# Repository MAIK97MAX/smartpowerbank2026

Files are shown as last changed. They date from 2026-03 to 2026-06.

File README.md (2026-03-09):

# Semesterproject 2026 - Smart Powerbank

## Authors
Jukic Malik & Sayfutdinov David - HTL Rankweil

## Goal 
The goal of this project is to design and build a smart power bank with USB-C charging, battery management and system monitoring.

## Features
- USB-C charging
- OLED display for battery status and system information
- ESP8266 module for web interface
- Battery monitoring and protection

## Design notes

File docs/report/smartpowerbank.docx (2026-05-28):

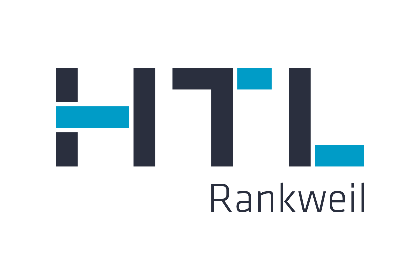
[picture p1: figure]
HTL Rankweil - Technik_begeistert

Semesterprojekt 2026

Smart Powerbank

Jukic Malik und Sayfutdinov David

HTL Rankweil

4AHEL

HWE-Übungen

Projektbetreuer: Herr Lauritsch

02.03.2026

# 1. Einleitung

## 1.1. Motivation

Mit zunehmender Nutzung von mobilen Geräten wie Smartphones, Tablets und Wearables steigt auch der Bedarf an mobiler und zuverlässiger Energieversorgung. Besonders im Alltag, auf Reisen oder im Outdoor-Bereich sind Powerbanks zu einem essenziellen Bestandteil der modernen Technik geworden.

Konventionelle Powerbanks erfüllen zwar ihre Aufgabe der mobilen Spannungsversorgung, doch weisen oft gewisse Einschränkungen auf. Informationen über den tatsächlichen Ladezustand, den Energieverbrauch oder die Effizienz stehen dem Nutzer meist nur eingeschränkt zur Verfügung.

Darüber hinaus besitzen viele handelsübliche Geräte keine detaillierte Überwachung relevanter Betriebsparameter wie Strom, Spannung oder Temperatur. Eine fehlende systematische Erfassung dieser Daten kann zu ineffizienter Energienutzung, verkürzter Lebensdauer der Akkuzellen sowie sicherheitstechnischen Risiken führen. Auch eine Aufzeichnung und Analyse des Betriebsverhaltens ist in herkömmlichen Lösungen in der Regel nicht vorgesehen.

Die Entwicklung einer Smart Powerbank bietet daher die Möglichkeit, Energiespeicherung, Leistungselektronik und intelligente Zustandsüberwachung in einem integrierten System zu vereinen. Neben einer stabilen und effizienten Spannungsregelung steht insbesondere die transparente Darstellung relevanter Systemparameter im Mittelpunkt.

Im Rahmen dieses Semesterprojekts wird daher eine intelligente Powerbank entwickelt, welche über ein erweitertes Energiemanagement verfügt sowie eine kontinuierliche Überwachung des Batteriezustandes ermöglicht.

## 1.2. Zielsetzung

Ziel dieses Semesterprojekts ist die Entwicklung und Realisierung einer intelligenten Powerbank auf Basis eines 1S-LiPo-Akkusystems mit einer nominalen Zellspannung von 3,7 V mit einer Kapazität von 8000 mAh.

Die Powerbank soll eine geregelte Ausgangsspannung von 5V bei einem maximalen Ausgangsstrom von 3 A bereitstellen. Die maximale Ausgangsleistung beträgt somit bis zu 15 W. Die Spannungswandlung erfolgt über eine geeignete DC/DC-Topologie mit einem angestrebten Gesamtwirkungsgrad von mindestens 80 % im Nennlastbereich.

Ein wesentlicher Bestandteil des Projekts ist die Implementierung eines erweiterten Energiemanagementsystems auf Basis eines ATmega328A-Mikrocontrollers. Ziel ist die kontinuierliche Erfassung und Verarbeitung relevanter Betriebsparameter, darunter:

– Ausgangsstrom und Ausgangsspannung mittels INA219-Messbausteinen
– Temperaturüberwachung des Akkusystems über einen NTC
– Berechnung der momentanen Ausgangsleistung
– Abschätzung des Ladezustands und der verbleibenden Entladedauer

Die erfassten Systemdaten sollen dem Nutzer über ein mehrstufiges Anzeigesystem zugänglich gemacht werden. Das Display umfasst verschiedene Betriebsmodi, darunter eine Startansicht mit Zeit- und Statusinformationen, eine Live-Ansicht der elektrischen Kenngrößen sowie eine detaillierte Batterieübersicht mit Zustands- und Verlaufsinformationen.

Zusätzlich wird ein ESP8266-Modul integriert, welches als Access Point fungiert und eine webbasierte Benutzeroberfläche bereitstellt. Ziel ist die drahtlose Anzeige von Betriebsdaten, Systeminformationen sowie gespeicherten Verlaufswerten. Die Zeitsynchronisation erfolgt über das Internet, wobei Datum und Uhrzeit mithilfe des ATmega328 dauerhaft gespeichert werden.

Neben der funktionalen Umsetzung steht insbesondere die systematische Integration von Leistungselektronik, Messdatenerfassung, Mikrocontroller-Steuerung und drahtloser Kommunikation im Fokus. Das Projekt verfolgt somit das Ziel, eine technisch fundierte, modular aufgebaute und praxisnahe Smart-Powerbank-Lösung zu realisieren.

## 1.3 Abgrenzungen des Projekts

Für dieses Projekt wurden bewusst einige Abgrenzungen (Nicht-Ziele) festgelegt welche nicht im Rahmen dieses Projekts liegen und zu unnötigen Verkomplizierungen und Ableitungen vom eigentlichen Thema führen würden.

Implementierung des USB-C Power-Delivery-(PD)-Protokolls
Die Ausgangsspannung wird bewusst auf eine feste 5V-Versorgung mit maximal 3A begrenzt. Die Umsetzung variabler Spannungsprofile gemäß USB-PD würde zusätzliche Protokoll-Controller sowie eine deutlich komplexere Leistungsregelung erfordern und liegt außerhalb des definierten Projektumfangs.

– Nutzung des ESP8266 als Router oder Internet-Gateway
Der ESP8266 dient ausschließlich zur Bereitstellung eines lokalen Access Points und zur Anzeige der webbasierten Benutzeroberfläche. Eine Weiterleitung von Internetverkehr oder eine Nutzung als Netzwerkinfrastrukturkomponente ist nicht vorgesehen.

– Smartphone-App-Entwicklung
Die Anzeige der Systemdaten erfolgt ausschließlich über das integrierte Display und ein webbasiertes Interface. Die Entwicklung einer Smartphone-App ist nicht Teil des Projekts.

## 1.4 Aufbau der Arbeit

In Kapitel 2 werden die notwendigen Technischen Grundlagen und Überlegungen für das System ermittelt und erläutert. In Kapitel 3…

# 2. Technische Grundlagen

## 2.1 Systemüberblick

Eine Powerbank unterteilt sich in 2 Hauptsysteme:

- Akkusystem (Akkuzelle, BMS, Laderegler, Fuel Cell)
- Spannungsregelung für den Ausgang

Zusätzlich zu diesen erfordert dieses Projekt weitere Systeme:

- Spannungs- und Strommessung
- Batterieüberwachung
- Live-Anzeige
- Steuerung
- Wi-Fi-Modul für Webserver-Anzeige

## 2.2 Realisierung

Vorerst veranschaulicht ein Blockschaltbild die Zusammenhänge und Kommunikation der Systeme.

### 2.2.1 Spannungs- und Strommessung

Für die Spannungs- und Strommessung der Ausgänge der Powerbank wird ein INA219 Current Monitor von Texas Instruments eingesetzt.

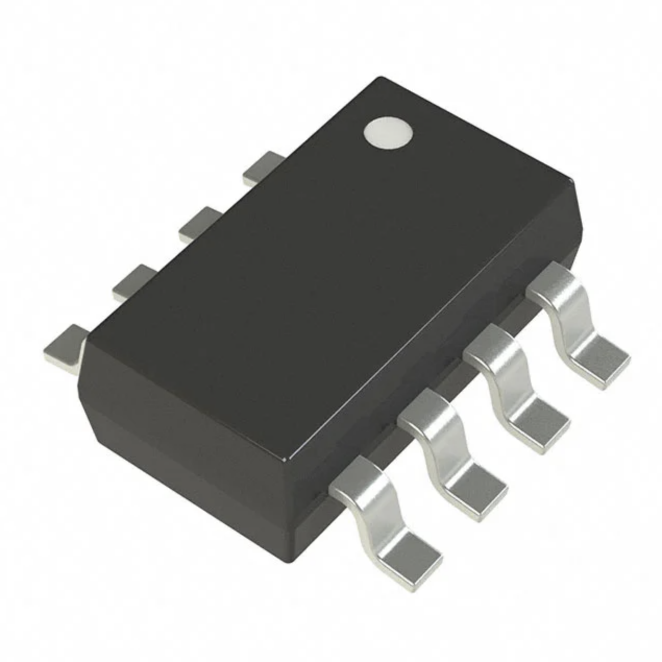
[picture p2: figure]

INA219

https://www.ti.com/product/de-de/INA219#tech-docs

Wichtige Kenndaten:

- I²C
- 12-Bit ADC
- Vs – 3,3V

Smart Powerbank Jukic M. & Sayfutdinov D.

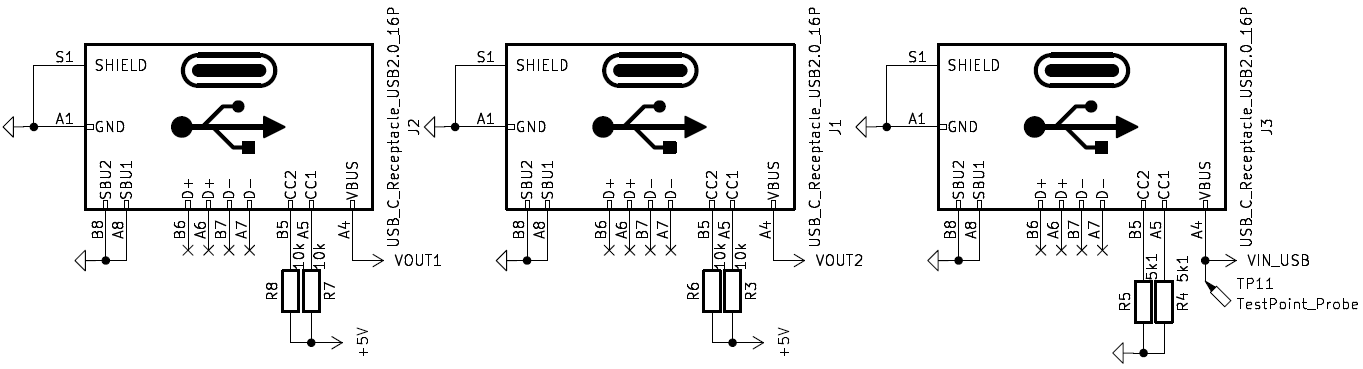
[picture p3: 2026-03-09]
docs/images/usbc-conn.png

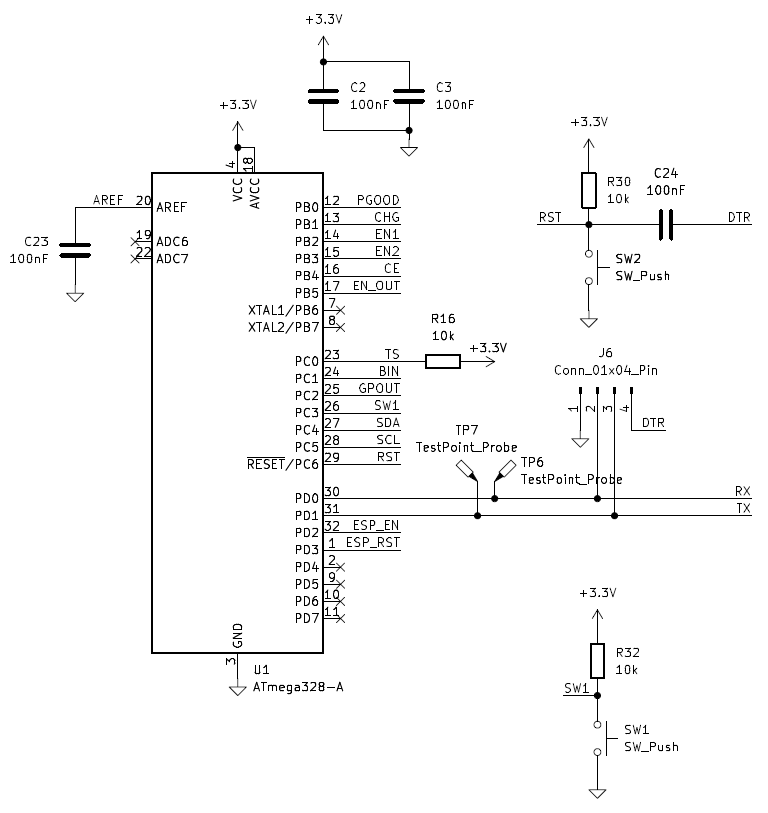
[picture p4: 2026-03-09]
docs/images/atmega328p.png

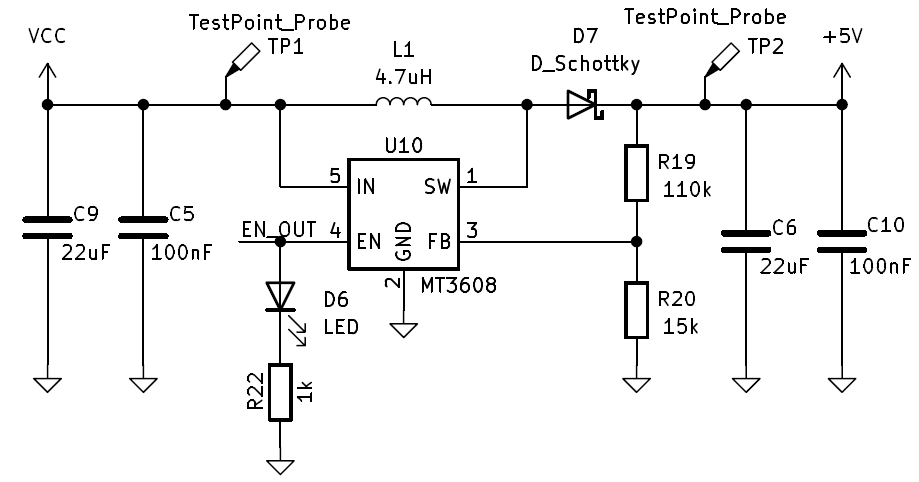
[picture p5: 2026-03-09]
docs/images/mt3608.png

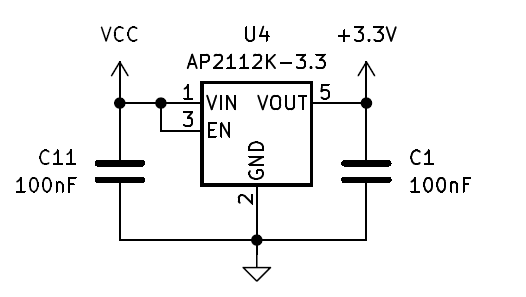
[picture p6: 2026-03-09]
docs/images/ap2112k.png

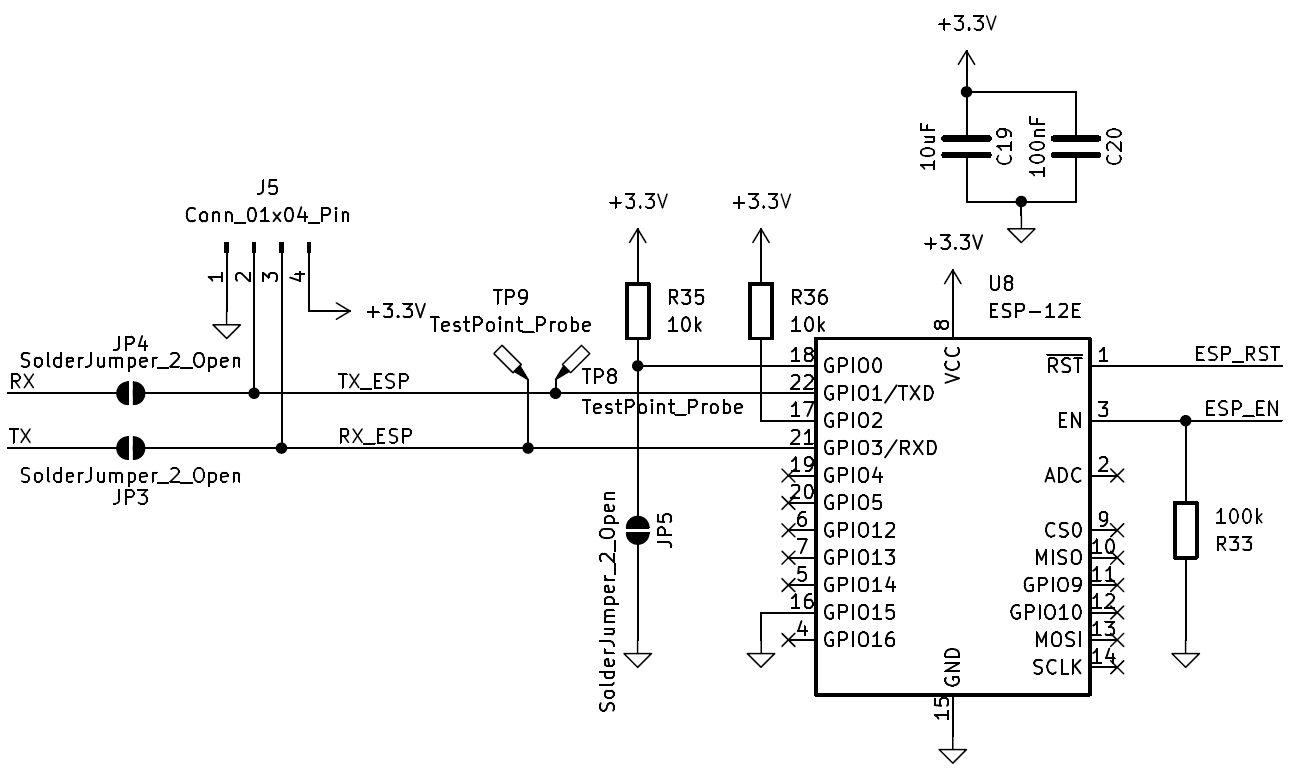
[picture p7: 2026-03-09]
docs/images/esp8266.png

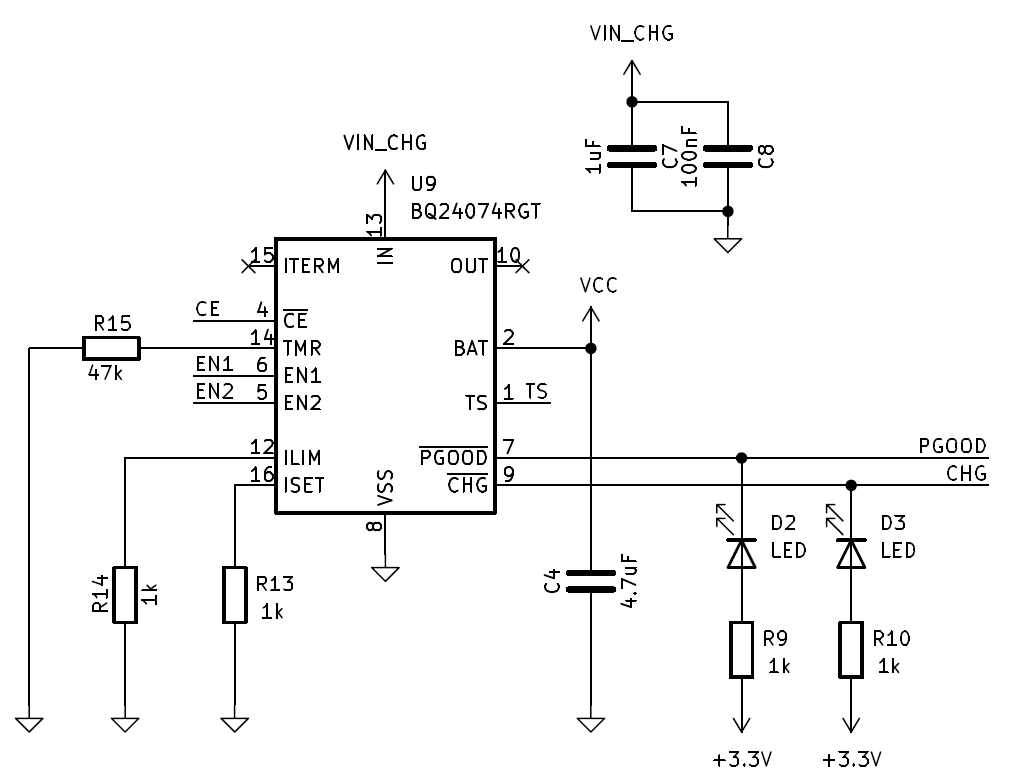
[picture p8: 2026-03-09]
docs/images/bq24074.png

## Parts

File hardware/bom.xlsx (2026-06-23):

Reference | Qty | Value | Footprint
C1,C2,C3,C4,C5,C6,C8,C12,C13,C15,C18,C20,C22 | 13 | 100nF | Capacitor_SMD:C_0603_1608Metric
C7,C17 | 2 | 1uF | Capacitor_SMD:C_0805_2012Metric
C9,C10,C19 | 3 | 10uF | Capacitor_SMD:C_0805_2012Metric
C11 | 1 | 470nF | Capacitor_SMD:C_0603_1608Metric
C14,C21 | 2 | 22uF | Capacitor_SMD:C_0805_2012Metric
C16 | 1 | 4.7uF | Capacitor_SMD:C_0603_1608Metric
D1,D2,D3,D5 | 4 | LED | LED_SMD:LED_0603_1608Metric
D4 | 1 | D_Schottky | Diode_SMD:D_SMA
D6 | 1 | n.b. | LED_SMD:LED_0603_1608Metric
J1,J2,J4 | 3 | USB_C_Receptacle_USB2.0_16P | Connector_USB:USB_C_Receptacle_GCT_USB4110
J3,J7 | 2 | Conn_01x04_Pin | Connector_PinHeader_2.54mm:PinHeader_1x04_P2.54mm_Vertical
J5 | 1 | Conn_01x04_Pin | Connector_PinSocket_2.54mm:PinSocket_1x04_P2.54mm_Vertical
J6 | 1 | Conn_01x03_Pin | Connector_PinHeader_2.54mm:PinHeader_1x03_P2.54mm_Vertical
JP1,JP2,JP3 | 3 | SolderJumper_2_Open | Jumper:SolderJumper-2_P1.3mm_Open_RoundedPad1.0x1.5mm
L1 | 1 | 4.7uH | Inductor_SMD:L_Coilcraft_XAL4030-XXX
R1,R2,R3,R4,R5,R6,R7,R20,R21 | 9 | 10k | Resistor_SMD:R_0603_1608Metric
R8,R9 | 2 | 5k1 | Resistor_SMD:R_0603_1608Metric
R10,R11 | 2 | 3.3k | Resistor_SMD:R_0603_1608Metric
R12,R14,R15 | 3 | 0.01 | Resistor_SMD:R_2512_6332Metric
R13,R16,R18,R19,R22,R23 | 6 | 1k | Resistor_SMD:R_0603_1608Metric
R17 | 1 | 47k | Resistor_SMD:R_0603_1608Metric
R24 | 1 | 110k | Resistor_SMD:R_0603_1608Metric
R25 | 1 | 15k | Resistor_SMD:R_0603_1608Metric
R26 | 1 | 100k | Resistor_SMD:R_0603_1608Metric
R27 | 1 | n.b. | Resistor_SMD:R_0603_1608Metric
SW1,SW2 | 2 | SW_Push | Button_Switch_SMD:SW_SPST_B3S-1000
TP1,TP2,TP3,TP4,TP5,TP6,TP7,TP8,TP9,TP10,TP11,TP12 | 12 | TestPoint_Probe | Connector_PinHeader_1.00mm:PinHeader_1x01_P1.00mm_Vertical
U1 | 1 | ATmega328-A | Package_QFP:TQFP-32_7x7mm_P0.8mm
U2 | 1 | AP2112K-3.3 | Package_TO_SOT_SMD:SOT-23-5
U3,U4 | 2 | INA219AxD | Package_SO:SOIC-8_3.9x4.9mm_P1.27mm
U5 | 1 | BQ27441-G1 | Package_SON:Texas_S-PDSO-N12
U6 | 1 | BQ24074RGT | Package_DFN_QFN:VQFN-16-1EP_3x3mm_P0.5mm_EP1.6x1.6mm
U7 | 1 | MT3608 | Package_TO_SOT_SMD:SOT-23-6
U8 | 1 | ESP-12E | RF_Module:ESP-12E

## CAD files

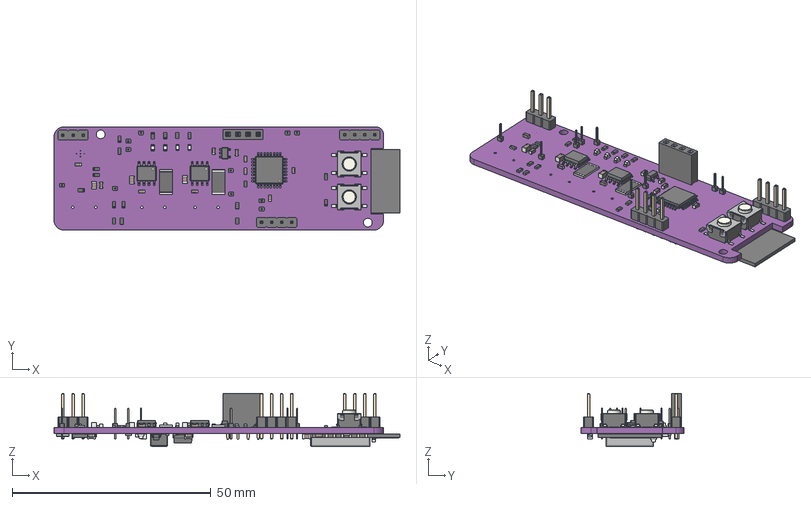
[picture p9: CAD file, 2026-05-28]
hardware/3dmodels/board.step
87.1 x 26.0 x 13.4 mm
TQFP-32_7x7mm_P0.8mm
R_0603_1608Metric x 24
SOIC-8_3.9x4.9mm_P1.27mm x 2
C_0603_1608Metric x 15
PinHeader_1x01_P1.00mm_Vertical x 11
SW_SPST_B3S-1000 x 2
LED_0603_1608Metric x 5
PinHeader_1x04_P2.54mm_Vertical x 2
C_0805_2012Metric x 7
SOT-23-5
R_2512_6332Metric x 3
PinHeader_1x03_P2.54mm_Vertical
PinSocket_1x04_P2.54mm_Vertical
L_Coilcraft_XAL4030-XXX
ESP-12E
D_SMA
SOT-23-6
Texas_S-PDSO-N12
Smart_Powerbank_Jukic_Sayfutdinov_PCB

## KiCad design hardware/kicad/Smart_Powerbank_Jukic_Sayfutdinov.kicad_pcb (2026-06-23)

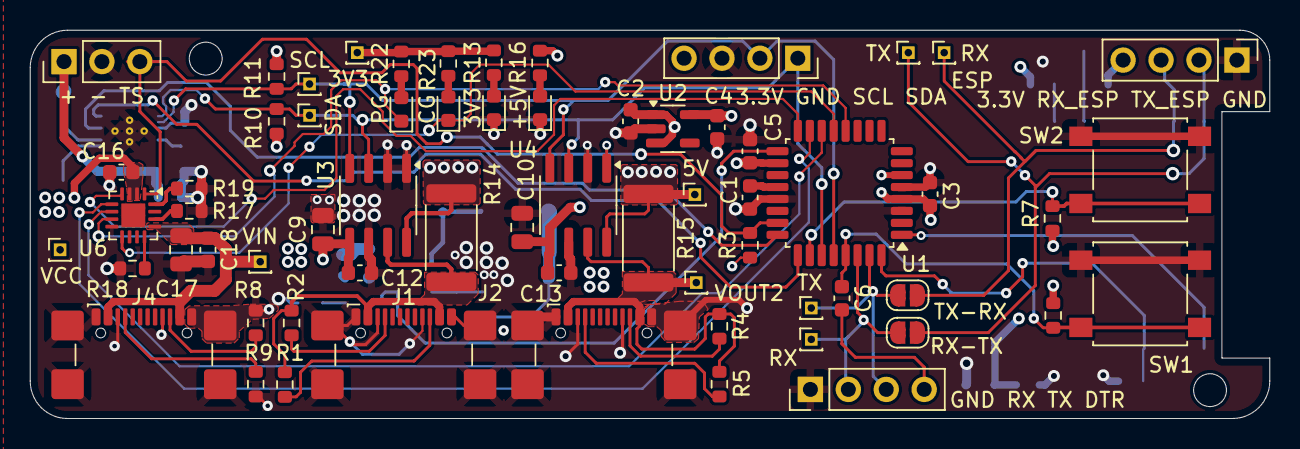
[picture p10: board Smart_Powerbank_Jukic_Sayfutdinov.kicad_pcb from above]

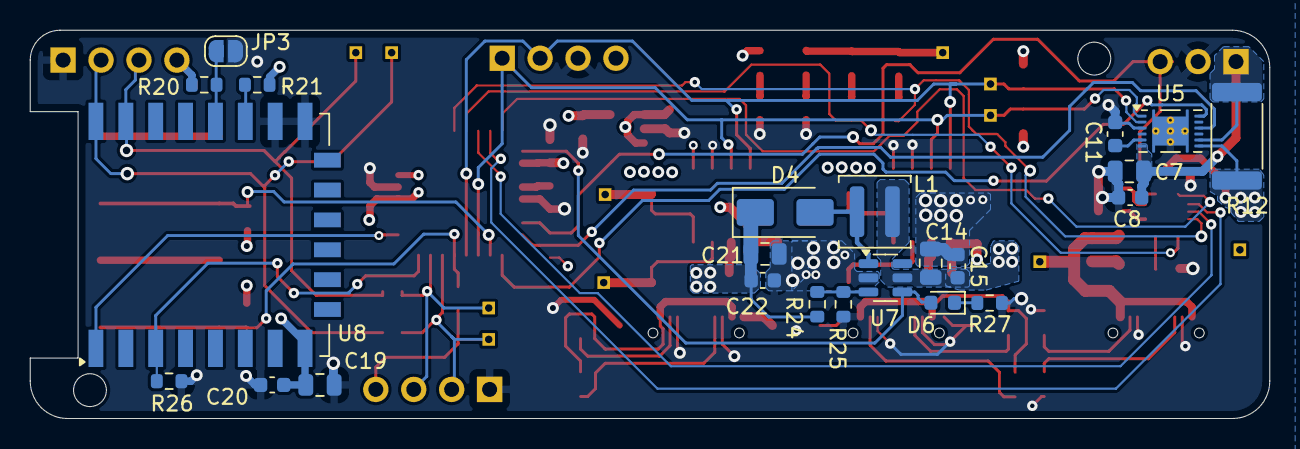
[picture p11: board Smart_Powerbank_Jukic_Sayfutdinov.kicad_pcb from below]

Board: 4 copper layers, 83.0 x 26.0 mm, 87 parts (23 on the bottom side), 48 nets.

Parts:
3.3V GND SCL SDA: Conn_01x04_Pin; PinSocket_1x04_P2.54mm_Vertical
3.3V RX_ESP TX_ESP GND: Conn_01x04_Pin; PinHeader_1x04_P2.54mm_Vertical
3V3: LED; LED_0603_1608Metric
3V3#2, 5V: TestPoint_Probe; PinHeader_1x01_P1.00mm_Vertical
+5V: LED; LED_0603_1608Metric
+ - TS: Conn_01x03_Pin; PinHeader_1x03_P2.54mm_Vertical
C1, C2, C3, C4, C5, C6, C8, C12, C13, C15, C18, C20, C22: 100nF; C_0603_1608Metric
C7, C17: 1uF; C_0805_2012Metric
C9, C10, C19: 10uF; C_0805_2012Metric
C11: 470nF; C_0603_1608Metric
C14, C21: 22uF; C_0805_2012Metric
C16: 4.7uF; C_0603_1608Metric
CG: LED; LED_0603_1608Metric
D4: D_Schottky; D_SMA
D6: n.b.; LED_0603_1608Metric
GND RX TX DTR: Conn_01x04_Pin; PinHeader_1x04_P2.54mm_Vertical
J1, J2, J4: USB_C_Receptacle_USB2.0_16P; USB_C_Receptacle_GCT_USB4110
JP3: SolderJumper_2_Open; SolderJumper-2_P1.3mm_Open_RoundedPad1.0x1.5mm
L1: 4.7uH; L_Coilcraft_XAL4030-XXX
PG: LED; LED_0603_1608Metric
R1, R2, R3, R4, R5, R6, R7, R20, R21: 10k; R_0603_1608Metric
R8, R9: 5k1; R_0603_1608Metric
R10, R11: 3.3k; R_0603_1608Metric
R12, R14, R15: 0.01; R_2512_6332Metric
R13, R16, R18, R19, R22, R23: 1k; R_0603_1608Metric
R17: 47k; R_0603_1608Metric
R24: 110k; R_0603_1608Metric
R25: 15k; R_0603_1608Metric
R26: 100k; R_0603_1608Metric
R27: n.b.; R_0603_1608Metric
RX: TestPoint_Probe; PinHeader_1x01_P1.00mm_Vertical
RX#2: TestPoint_Probe; PinHeader_1x01_P1.00mm_Vertical
RX-TX: SolderJumper_2_Open; SolderJumper-2_P1.3mm_Open_RoundedPad1.0x1.5mm
SCL: TestPoint_Probe; PinHeader_1x01_P1.00mm_Vertical
SDA: TestPoint_Probe; PinHeader_1x01_P1.00mm_Vertical
SW1, SW2: SW_Push; SW_SPST_B3S-1000
TX: TestPoint_Probe; PinHeader_1x01_P1.00mm_Vertical
TX#2: TestPoint_Probe; PinHeader_1x01_P1.00mm_Vertical
TX-RX: SolderJumper_2_Open; SolderJumper-2_P1.3mm_Open_RoundedPad1.0x1.5mm
U1: ATmega328-A; TQFP-32_7x7mm_P0.8mm
U2: AP2112K-3.3; SOT-23-5
U3, U4: INA219AxD; SOIC-8_3.9x4.9mm_P1.27mm
U5: BQ27441-G1; Texas_S-PDSO-N12
U6: BQ24074RGT; VQFN-16-1EP_3x3mm_P0.5mm_EP1.6x1.6mm
U7: MT3608; SOT-23-6
U8: ESP-12E
VCC: TestPoint_Probe; PinHeader_1x01_P1.00mm_Vertical
VIN: TestPoint_Probe; PinHeader_1x01_P1.00mm_Vertical
VOUT2: TestPoint_Probe; PinHeader_1x01_P1.00mm_Vertical

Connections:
+3.3V: 3.3V GND SCL SDA.4, 3.3V RX_ESP TX_ESP GND.4, 3V3#2.1, C3.1, C4.1, C5.1, C9.1, C10.1, C12.1, C13.1, C19.1, C20.1, R3.2, R6.2, R7.2, R10.1, R11.1, R13.2, R20.2, R21.2, R22.2, R23.2, U1.4 (VCC), U1.6 (VCC), U1.18 (AVCC), U2.5 (VOUT), U3.5 (VS), U4.1 (A1), U4.5 (VS), U8.8 (VCC)
+5V: 5V.1, C21.1, C22.1, D4.1 (K), R14.1, R15.1, R16.2, R24.1, U3.8 (IN+), U4.8 (IN+)
/AREF: C1.1, U1.20 (AREF)
/BAT+: + - TS.1, C7.1, C8.1, R12.1, U5.6 (BAT), U5.8 (SRP)
/BIN: U1.24 (PC1), U5.10 (BIN)
/CE: U1.16 (PB4), U6.4 (~CE)
/CHG: CG.1 (K), U1.13 (PB1), U6.9 (~CHG)
/DTR: C6.2, GND RX TX DTR.4
/EN1: U1.14 (PB2), U6.6 (EN1)
/EN2: U1.15 (PB3), U6.5 (EN2)
/EN_OUT: D6.2 (A), U1.17 (PB5), U7.4 (EN)
/ESP_EN: R26.1, U1.32 (PD2), U8.3 (EN)
/ESP_RST: U1.1 (PD3), U8.1 (~RST)
/FB: R24.2, R25.1, U7.3 (FB)
/GPOUT: U1.25 (PC2), U5.12 (GPOUT)
/ILIM: R18.2, U6.12 (ILIM)
/ISET: R19.1, U6.16 (ISET)
/PGOOD: PG.1 (K), U1.12 (PB0), U6.7 (~PGOOD)
/RST: C6.1, R6.1, SW1.1, U1.29 (~RESET/PC6)
/RX: GND RX TX DTR.2, RX.1, RX-TX.1 (A), U1.30 (PD0)
/RX_ESP: 3.3V RX_ESP TX_ESP GND.3, RX#2.1, TX-RX.2 (B), U8.21 (GPIO3/RXD)
/SCL: 3.3V GND SCL SDA.2, R11.2, SCL.1, U1.28 (PC5), U3.4 (SCL), U4.4 (SCL), U5.2 (SCL)
/SDA: 3.3V GND SCL SDA.1, R10.2, SDA.1, U1.27 (PC4), U3.3 (SDA), U4.3 (SDA), U5.1 (SDA)
/SW: D4.2 (A), L1.2, U7.1 (SW)
/SW_MODE: R7.1, SW2.1, U1.26 (PC3)
/TMR: R17.2, U6.14 (TMR)
/TS: + - TS.3, R3.1, U1.23 (PC0), U6.1 (TS)
/TX: GND RX TX DTR.3, TX#2.1, TX-RX.1 (A), U1.31 (PD1)
/TX_ESP: 3.3V RX_ESP TX_ESP GND.2, RX-TX.2 (B), TX.1, U8.22 (GPIO1/TXD)
/VDD: C11.1, U5.5 (V_{DD})
GND: 3.3V GND SCL SDA.3, 3.3V RX_ESP TX_ESP GND.1, 3V3.1 (K), +5V.1 (K), + - TS.2, C1.2, C2.2, C3.2, C4.2, C5.2, C7.2, C8.2, C9.2, C10.2, C11.2, C12.2, C13.2, C14.2, C15.2, C16.1, C17.2, C18.2, C19.2, C20.2, C21.2, C22.2, GND RX TX DTR.1, J1.A1 (GND), J1.A8 (SBU1), J1.A12 (GND), J1.B1 (GND), J1.B8 (SBU2), J1.B12 (GND), J1.S1 (SHIELD), J2.A1 (GND), J2.A8 (SBU1), J2.A12 (GND), J2.B1 (GND), J2.B8 (SBU2), J2.B12 (GND), J2.S1 (SHIELD), J4.A1 (GND), J4.A8 (SBU1), J4.A12 (GND), J4.B1 (GND), J4.B8 (SBU2), J4.B12 (GND), J4.S1 (SHIELD), JP3.1 (A), R8.1, R9.2, R17.1, R18.1, R19.2, R25.2, R26.2, R27.1, SW1.2, SW2.2, U1.3 (GND), U1.5 (GND), U1.21 (GND), U2.2 (GND), U3.1 (A1), U3.2 (A0), U3.6 (GND), U4.2 (A0), U4.6 (GND), U5.3 (V_{SS}), U5.13 (PAD), U6.8 (VSS), U6.17 (VSS), U7.2 (GND), U8.15 (GND), U8.16 (GPIO15)
unnamed: 3V3.2 (A), R13.1
unnamed: +5V.2 (A), R16.1
unnamed: PG.2 (A), R22.1
unnamed: CG.2 (A), R23.1
unnamed: D6.1 (K), R27.2
unnamed: J1.A5 (CC1), R2.1
unnamed: J1.B5 (CC2), R1.2
unnamed: J2.A5 (CC1), R5.1
unnamed: J2.B5 (CC2), R4.2
unnamed: J4.A5 (CC1), R9.1
unnamed: J4.B5 (CC2), R8.2
unnamed: JP3.2 (B), R20.1, U8.18 (GPIO0)
unnamed: R21.1, U8.17 (GPIO2)
VCC: C2.1, C14.1, C15.1, C16.2, L1.1, R12.2, U2.1 (VIN), U2.3 (EN), U5.7 (SRN), U6.2 (BAT), U6.3 (BAT), U7.5 (IN), VCC.1
VIN_USB: C17.1, C18.1, J4.A4 (VBUS), J4.A9 (VBUS), J4.B4 (VBUS), J4.B9 (VBUS), U6.13 (IN), VIN.1
VOUT1: J1.A4 (VBUS), J1.A9 (VBUS), J1.B4 (VBUS), J1.B9 (VBUS), R1.1, R2.2, R14.2, U3.7 (IN-)
VOUT2: J2.A4 (VBUS), J2.A9 (VBUS), J2.B4 (VBUS), J2.B9 (VBUS), R4.1, R5.2, R15.2, U4.7 (IN-), VOUT2.1

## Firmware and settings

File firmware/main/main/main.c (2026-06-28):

/*
 * main.c
 *
 * Created: 25.06.2026 22:47:29
 * Author : Malik
 */ 

#define F_CPU 8000000UL

#define INA_REG_SHUNT_V 0x01
#define INA_REG_BUS_V 0x02
#define INA_REG_CURRENT 0x04
#define INA_REG_CALIBRATION 0x05
#define INA_CALIBRATION 0x1000
#define INA1_W 0x80
#define INA1_R 0x81
#define INA2_W 0x88
#define INA2_R 0x89

#define BUTTON PC3

#include <avr/io.h>
#include <util/delay.h>
#include "molibdisplay.h"

//-----------------------------INA219---------------------------------//

uint16_t ina_read_reg(uint8_t addr_w, uint8_t addr_r, uint8_t reg)
{
	uint16_t value;

	if (!twi_s_start(addr_w))
	{
		twi_s_stop();
		return 0xFFFF;
	}

	if (!twi_s_write(reg))
	{
		twi_s_stop();
		return 0xFFFF;
	}

	if (!twi_s_rep_start(addr_r))
	{
		twi_s_stop();
		return 0xFFFF;
	}

	value = ((uint16_t)twi_s_read(ACK)) << 8;
	value |= twi_s_read(NACK);

	twi_s_stop();

	return value;
}

uint8_t ina_write_reg(uint8_t addr_w, uint8_t reg, uint16_t value) 
{
	if(!twi_s_start(addr_w)) 
	{
		twi_s_stop();
		return 0;
	}
	
	if(!twi_s_write(reg))
	{
		twi_s_stop();
		return 0;
	}
	
	if(!twi_s_write((uint8_t)(value >> 8)))
	{
		twi_s_stop();
		return 0;
	}
	
	if(!twi_s_write((uint8_t)value))
	{
		twi_s_stop();
		return 0;
	}
	
	twi_s_stop();
	
	return 1;
}

float ina_bus_voltage(uint8_t addr_w, uint8_t addr_r)
{
	uint16_t raw = ina_read_reg(addr_w, addr_r, INA_REG_BUS_V);

	raw >>= 3;              // Bits 15..3 enthalten die Busspannung
	return raw * 0.004;    // 4 mV pro Bit
}

int16_t ina_shunt_raw(uint8_t addr_w, uint8_t addr_r)
{
	return (int16_t)ina_read_reg(addr_w, addr_r, INA_REG_SHUNT_V);
}

int16_t ina_current(uint8_t addr_w, uint8_t addr_r)
{
	return (int16_t)ina_read_reg(addr_w, addr_r, INA_REG_CURRENT);
}

//-----------------------------init------------------------------//

void init() {
	DDRB |= (1 << PB5) | (1 << PB2) | (1 << PB3);
	PORTB |= (1 << PB5) | (1 << PB3);
	PORTB &= ~(1 << PB2);
	
	DDRC &= ~(1 << BUTTON);
	
	DDRC &= ~(1<<PC2);   // PC2 as input (GPOUT)
	DDRC  |=  (1<<PC1);  // PC1 as output (BIN)
	PORTC &= ~(1<<PC1);  // PC1 low = battery present
}

void ina_init()
{
	ina_write_reg(INA1_W, INA_REG_CALIBRATION, INA_CALIBRATION);
	ina_write_reg(INA2_W, INA_REG_CALIBRATION, INA_CALIBRATION);
	
	_delay_ms(1);
}

//-----------------------------MAIN------------------------------//

int main(void)
{	
	init();
	display_init();
	ina_init();
	
	uint8_t screen = 0;
	
	display_clear();

    while (1) 
    {   
		if (!(PINC & (1 << BUTTON)))
		{
			_delay_ms(30);

			if (!(PINC & (1 << BUTTON)))
			{
				screen ^= 1;

				while (!(PINC & (1 << BUTTON)))
				{
				}

				_delay_ms(30);
			}
		}
		
		float u1 = ina_bus_voltage(INA1_W, INA1_R);
		float u2 = ina_bus_voltage(INA2_W, INA2_R);
		
		int16_t i1 = ina_current(INA1_W, INA1_R);
		int16_t i2 = ina_current(INA2_W, INA2_R);
		
		if (screen == 0)
		{
			display_printf_pos(0, 0, "SmartPowerbank");
			display_printf_pos(0, 1, "HTL Rankweil");
			display_printf_pos(0, 3, "Malik Jukic &");
			display_printf_pos(0, 4, "David Sayfutdinov");
		} 
		else
		{
			display_clear();
			display_printf_pos(0, 0, "OUT1:%d.%02dV",
			(int)u1,
			((int)(u1 * 100)) % 100);

			display_printf_pos(0, 3, "OUT2:%d.%02dV",
			(int)u2,
			((int)(u2 * 100)) % 100);
			
			display_printf_pos(0,1, "I1:%dmA", i1);
			display_printf_pos(0,4, "I2:%dmA", i2);
			
			_delay_ms(1000);
		}		
    }
}

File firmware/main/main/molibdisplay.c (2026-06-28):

/*-------------------------------------------------------------------------*\
| Datei:        molibdisplay.c
| Version:      1.0
| Projekt:      Display-Bibliothek fuer die MEGACARD V5.5
| Beschreibung: Bibliotheksfunktionen (Implementierung)
| Schaltung:    MEGACARD V5.5
| Autor:        D.I. Leopold Moosbrugger
| Erstellung:   3.3.2022
|
| Aenderung:
\*-------------------------------------------------------------------------*/
#define F_CPU 8000000UL

#include <avr/io.h>
#include <avr/pgmspace.h>
#include <stdio.h>
#include <stdarg.h>
#include <util/delay.h>
#include "molibdisplay.h" // Schnittstellendefinitionen


// Sevice Bereich SW-I2C Schnittstelle für das Display------------------------------


#ifdef TWI_S_FAST
   // Pause TWI 400kHz / I2C Fast 
   // 1us
   #define TWI_S_DELAY1() _delay_us(0.7)
   // 2us
   #define TWI_S_DELAY2() _delay_us(1.5)
#else
   // Pause TWI 100kHz / I2C Standard
   // 1us
   #define TWI_S_DELAY1() _delay_us(5.0)
   // 2us
   #define TWI_S_DELAY2() _delay_us(5.0)
#endif

#define P_SCL_LIN (1<<PSCL_TWI_S)
#define P_SDA_LIN (1<<PSDA_TWI_S)


// Definitionen fuer die Tackt- und die Datenleitung
// Open Drain
//    Low  => DDR->Ausgang, PORT->Low (0)
//    High => DDR->Eingang, PORT->kein PU (0) 
#define SDA_PSEC  (PRT_TWI_S &= ~P_SDA_LIN)
#define SDA_HIGH  (DDR_TWI_S &= ~P_SDA_LIN)
#define SDA_LOW   (DDR_TWI_S |=  P_SDA_LIN)
#define SDA_IN    (PIN_TWI_S & P_SDA_LIN)

//#define SCL_PSEC  (PRT_TWI_S &= ~P_SCL_LIN)
//#define SCL_HIGH  (DDR_TWI_S &= ~P_SCL_LIN)
//#define SCL_LOW   (DDR_TWI_S |=  P_SCL_LIN)
//#define SCL_IN    (PIN_TWI_S & P_SCL_LIN)


// Definitionen fuer die Tackt- und die Datenleitung
// Aktive Leitunge (Testbetrieb ohne Baustein)
//    Low  => DDR->Ausgang, PORT->Low (0)
//    High => DDR->Ausgang, PORT->High (1)
//#define SDA_PSEC  (DDR_TWI_S |=  P_SDA_LIN)
//#define SDA_HIGH  (PRT_TWI_S |=  P_SDA_LIN)
//#define SDA_LOW   (PRT_TWI_S &= ~P_SDA_LIN)
//#define SDA_IN    (PIN_TWI_S & P_SDA_LIN)

#define SCL_PSEC  (DDR_TWI_S |=  P_SCL_LIN)
#define SCL_HIGH  (PRT_TWI_S |=  P_SCL_LIN)
#define SCL_LOW   (PRT_TWI_S &= ~P_SCL_LIN)
#define SCL_IN    (PIN_TWI_S & P_SCL_LIN)


// Init TWI
void twi_s_init(void)
{
/* SCL XXX/''''
   SDA XX/'''''
*/

   SDA_HIGH; // SDA_HIGH;
   SDA_PSEC;
   SCL_HIGH; // SCL_HIGH;
   SCL_PSEC;
}

// Start TWI
uint8_t twi_s_start(uint8_t address)
{
/* SCL ''''\...
   SDA '\......
*/
   SDA_PSEC;
   SCL_PSEC;
   SDA_LOW; TWI_S_DELAY2();
   SCL_LOW; TWI_S_DELAY2();
   
   return twi_s_write(address);
}

uint8_t twi_s_rep_start(uint8_t address)
{
	// Nach twi_s_write() ist SCL noch LOW.
	// Für Repeated Start: SDA loslassen, SCL HIGH,
	// dann SDA bei HIGH auf LOW ziehen.

	SDA_PSEC;
	SCL_PSEC;

	SDA_HIGH;
	SCL_HIGH;
	TWI_S_DELAY2();

	SDA_LOW;
	TWI_S_DELAY2();

	SCL_LOW;
	TWI_S_DELAY2();

	return twi_s_write(address);
}

// Stop TWI
void twi_s_stop(void)
{
/* SCL ..../''''''
   SDA '\....../''
*/   
   SDA_PSEC;
   SCL_PSEC;
   SDA_LOW;  TWI_S_DELAY2();
   SCL_HIGH; TWI_S_DELAY2();
   SDA_HIGH; TWI_S_DELAY2();
}

// TWI schreiben
uint8_t twi_s_write(uint8_t data)
{
   uint8_t i;
   uint8_t hlp;
   uint8_t t;

   SDA_PSEC;
   SCL_PSEC;
  
/* SCL .../'0'\../'1'\../'2'\../'3'\../'4'\../'5'\../'6'\../'7'\../'A\
   SDA 'X======X======X======X======X======X======X======X======/'''''
*/  
   for (i=0;i<8;i++)
   {  // 8 Bit ausgeben
      if ((data & (1<<7)) != 0)
         SDA_HIGH; // wenn Bit gesetzt
      else
         SDA_LOW;  // wenn Bit nicht gesetzt

      data <<= 1;  // Bit schieben, 7 bis 0
      TWI_S_DELAY1();
      SCL_HIGH;
	  t = 255; while ((SCL_IN == 0) && (--t));
      TWI_S_DELAY2();
      SCL_LOW;
   }

   SDA_HIGH;
   TWI_S_DELAY1();
   SCL_HIGH;
   t = 255; while ((SCL_IN == 0) && (--t));
   TWI_S_DELAY1();

   if (SDA_IN == 0) // Testen SDA auf Acknowledge low
      hlp = ACK;    // Flag Ack setzen
   else
      hlp = NACK;   // sonst Flag Ack loeschen

   SCL_LOW;
   
   return hlp;
}

// TWI Byte lesen

uint8_t twi_s_read(uint8_t ack)
{
   uint8_t data = 0;
   uint8_t i;
   uint8_t t;

   SDA_PSEC;
   SCL_PSEC;

/* SCL ./'0\../'1\../'2\../'3\../'4\../'5\../'6\../'7\../''\.
   SDA ===D=====D=====D=====D=====D=====D=====D=====D=A=====/
*/
   for (i=0;i<8;i++)
   {  // 8 Bit ausgeben
      data <<= 1;			// Bit schieben, 7 bis 0
      TWI_S_DELAY1();
      SCL_HIGH;
	  t = 255; while ((SCL_IN == 0) && (--t));
      TWI_S_DELAY1();
      if (SDA_IN != 0) // Testen SDA auf high
         data |= 1;    // wenn high, Bit 0 setzen
      SCL_LOW;
   }

   if (ack)
      SDA_LOW;  // Acknowledge
   else
      SDA_HIGH;  // No Acknowledge
   
   TWI_S_DELAY1();
   SCL_HIGH;
   t = 255; while ((SCL_IN == 0) && (--t));
   TWI_S_DELAY2();
   SCL_LOW;
   SDA_HIGH;

   return data;  // Daten zurückgeben
}

void bq_bus_reset(void)
{
	uint8_t i;
	
	// clock out up to 9 pulses to release a stuck SDA
	DDR_TWI_S  |=  P_SCL_LIN;   // SCL output
	DDR_TWI_S  &= ~P_SDA_LIN;   // SDA input
	PRT_TWI_S  &= ~P_SCL_LIN;

	for (i = 0; i < 9; i++)
	{
		PRT_TWI_S |=  P_SCL_LIN;
		_delay_us(5);
		PRT_TWI_S &= ~P_SCL_LIN;
		_delay_us(5);
	}

	// issue a stop
	DDR_TWI_S |= P_SDA_LIN;
	_delay_us(5);
	PRT_TWI_S |= P_SCL_LIN;
	_delay_us(5);
	DDR_TWI_S &= ~P_SDA_LIN;
	_delay_us(5);
}

// Sevice Bereich SW-I2C Schnittstelle für das Display------------------------------

// Zeichnesatz-Code-----------------------------------------------------------------
// Auswahl des Zeichensatzes
//#define FONT_7x8
#define FONT_5x8

#if defined (FONT_7x8)
// erstes Zeichen, letztes Zeichen
// Fontbreite, Fonthoehe, Fontspacing
FontParam_t fontParam = {32, 129, 7, 8, 1};
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

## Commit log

2026-03-09 added KiCAD-Files
    [Smart_Powerbank_Jukic_Sayfutdinov.kicad_pcb, Smart_Powerbank_Jukic_Sayfutdinov.kicad_sch]
2026-03-12 Finished component placement, i2c routing and uart routing
    [Smart_Powerbank_Jukic_Sayfutdinov.kicad_pcb]
2026-04-09 finished atmega logic pin routing and revised power layout
    [Smart_Powerbank_Jukic_Sayfutdinov.kicad_pcb]
2026-04-30 cleanup and prep for ordering
    [Smart_Powerbank_Jukic_Sayfutdinov.kicad_pcb]
2026-04-30 Added mounting holes and fixed drc issues
    [Smart_Powerbank_Jukic_Sayfutdinov.kicad_pcb]
2026-05-07 changed silkscreen labels and created gerbers
    [Smart_Powerbank_Jukic_Sayfutdinov.kicad_pcb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]
2026-05-07 made final changes; added gerbers.zip; orderd parts from inventory
    [Smart_Powerbank_Jukic_Sayfutdinov.csv, Smart_Powerbank_Jukic_Sayfutdinov.kicad_pcb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]
2026-05-28 created .step file of board
    [board.step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]
2026-06-23 created .stl file of board
    [Smart_Powerbank_Jukic_Sayfutdinov.kicad_pcb, bom.xlsx]
2026-06-28 burned bootloader, added firmware for oled display and voltage/current meas
